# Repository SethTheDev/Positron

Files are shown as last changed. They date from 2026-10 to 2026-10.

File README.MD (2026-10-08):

# Resonance
An open-source USB-C Audio Interface powered by an STM32F411 and using a Cirrus Logic CS43198 DAC chip.
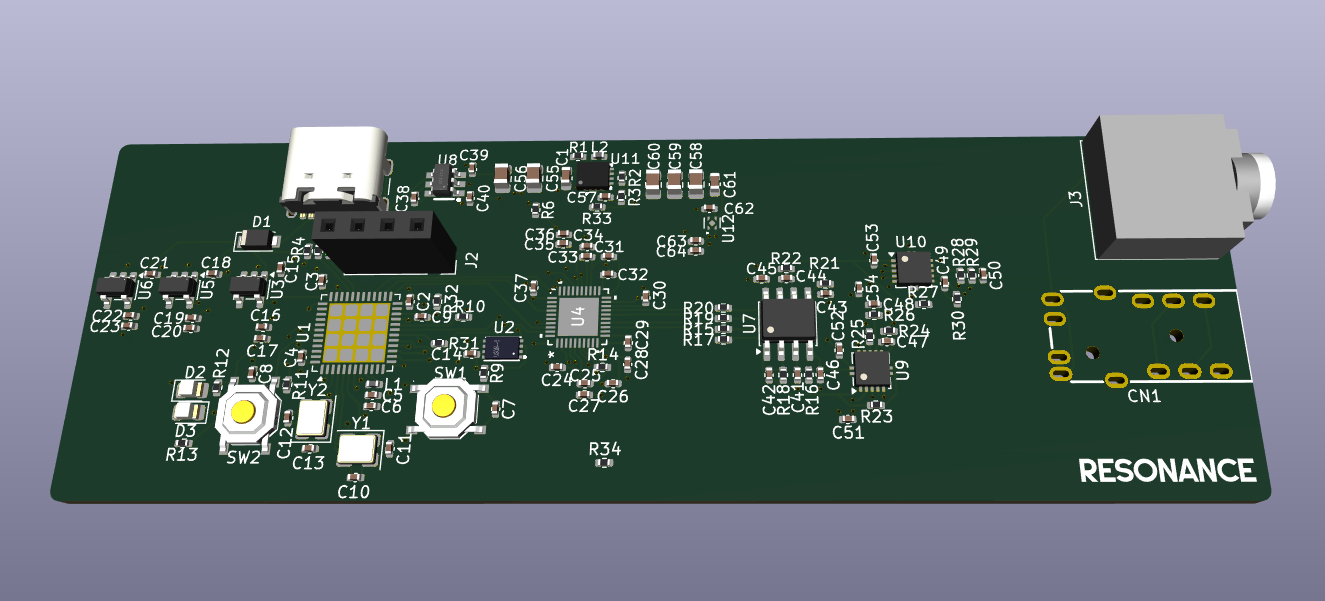
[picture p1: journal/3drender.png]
3d render


This is my magnum opus (*seriously*)

## Features
* STM32F411 microcontroller for USB audio
* Cirrus Logic CS43198 DAC with pseudo-differential output
* OPA1622 Differential Headphone Amplifier

## Rough Timeline
* (May 2026) - Raspberry Pi Pico + PCM5102
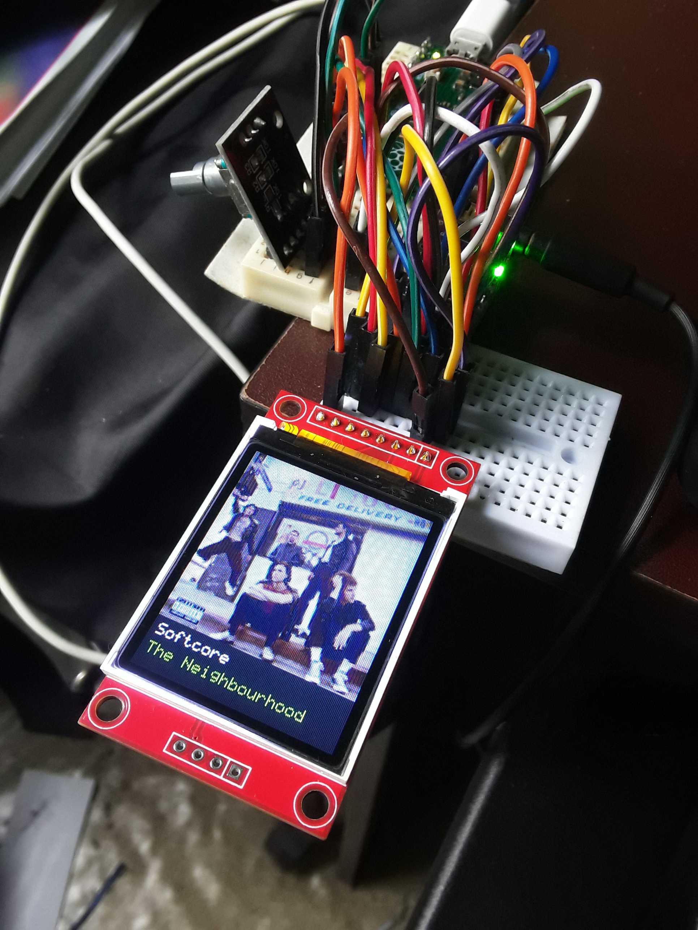
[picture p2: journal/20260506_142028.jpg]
prototype

* (August 2026) - Stuck with the Pico because of it's versatility, however I decided to use a professional Cirrus Logic CS43198 chip
* (September 2026) - Switch to an STM32H743 (way too overpowered, what was I thinking), and included a CS5361 ADC with dual-channel op-amps for two mic inputs
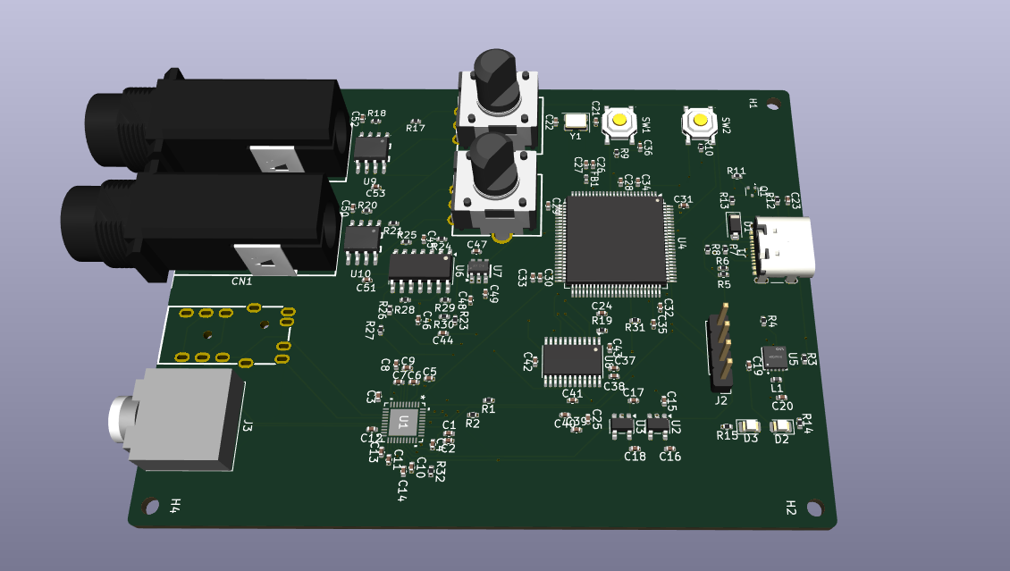
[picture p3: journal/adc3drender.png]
adc prototype

* (October 2026) - Realized I would face a lot of power-related problems so I downgraded to an STM32F411 and kept only the CS43198 DAC. Also completely revamped the schematic so it would be easy to read
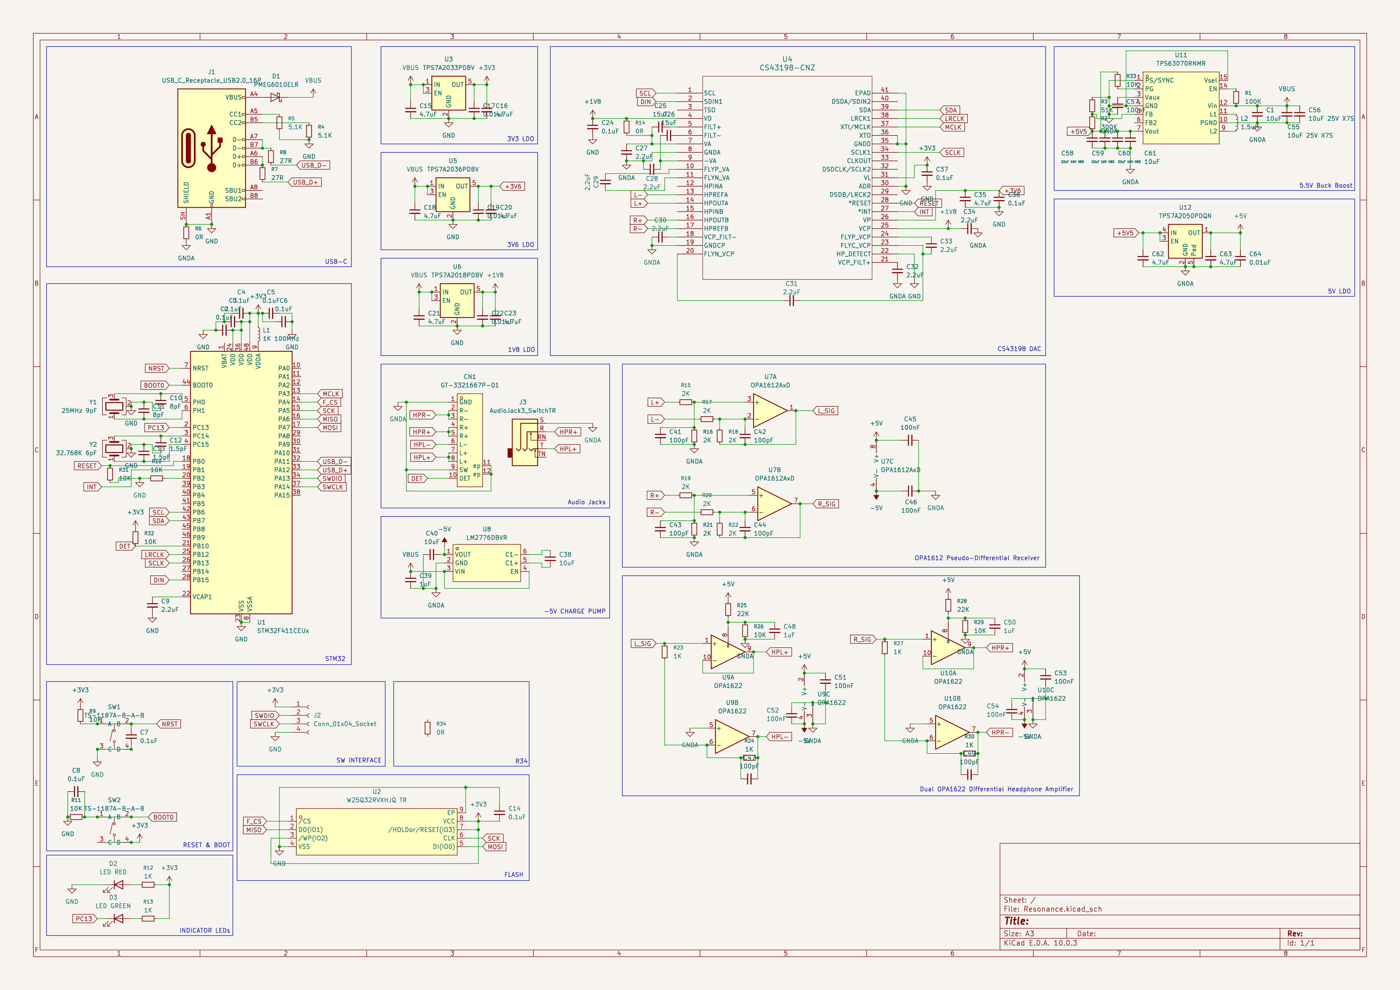
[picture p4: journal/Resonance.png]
schematic


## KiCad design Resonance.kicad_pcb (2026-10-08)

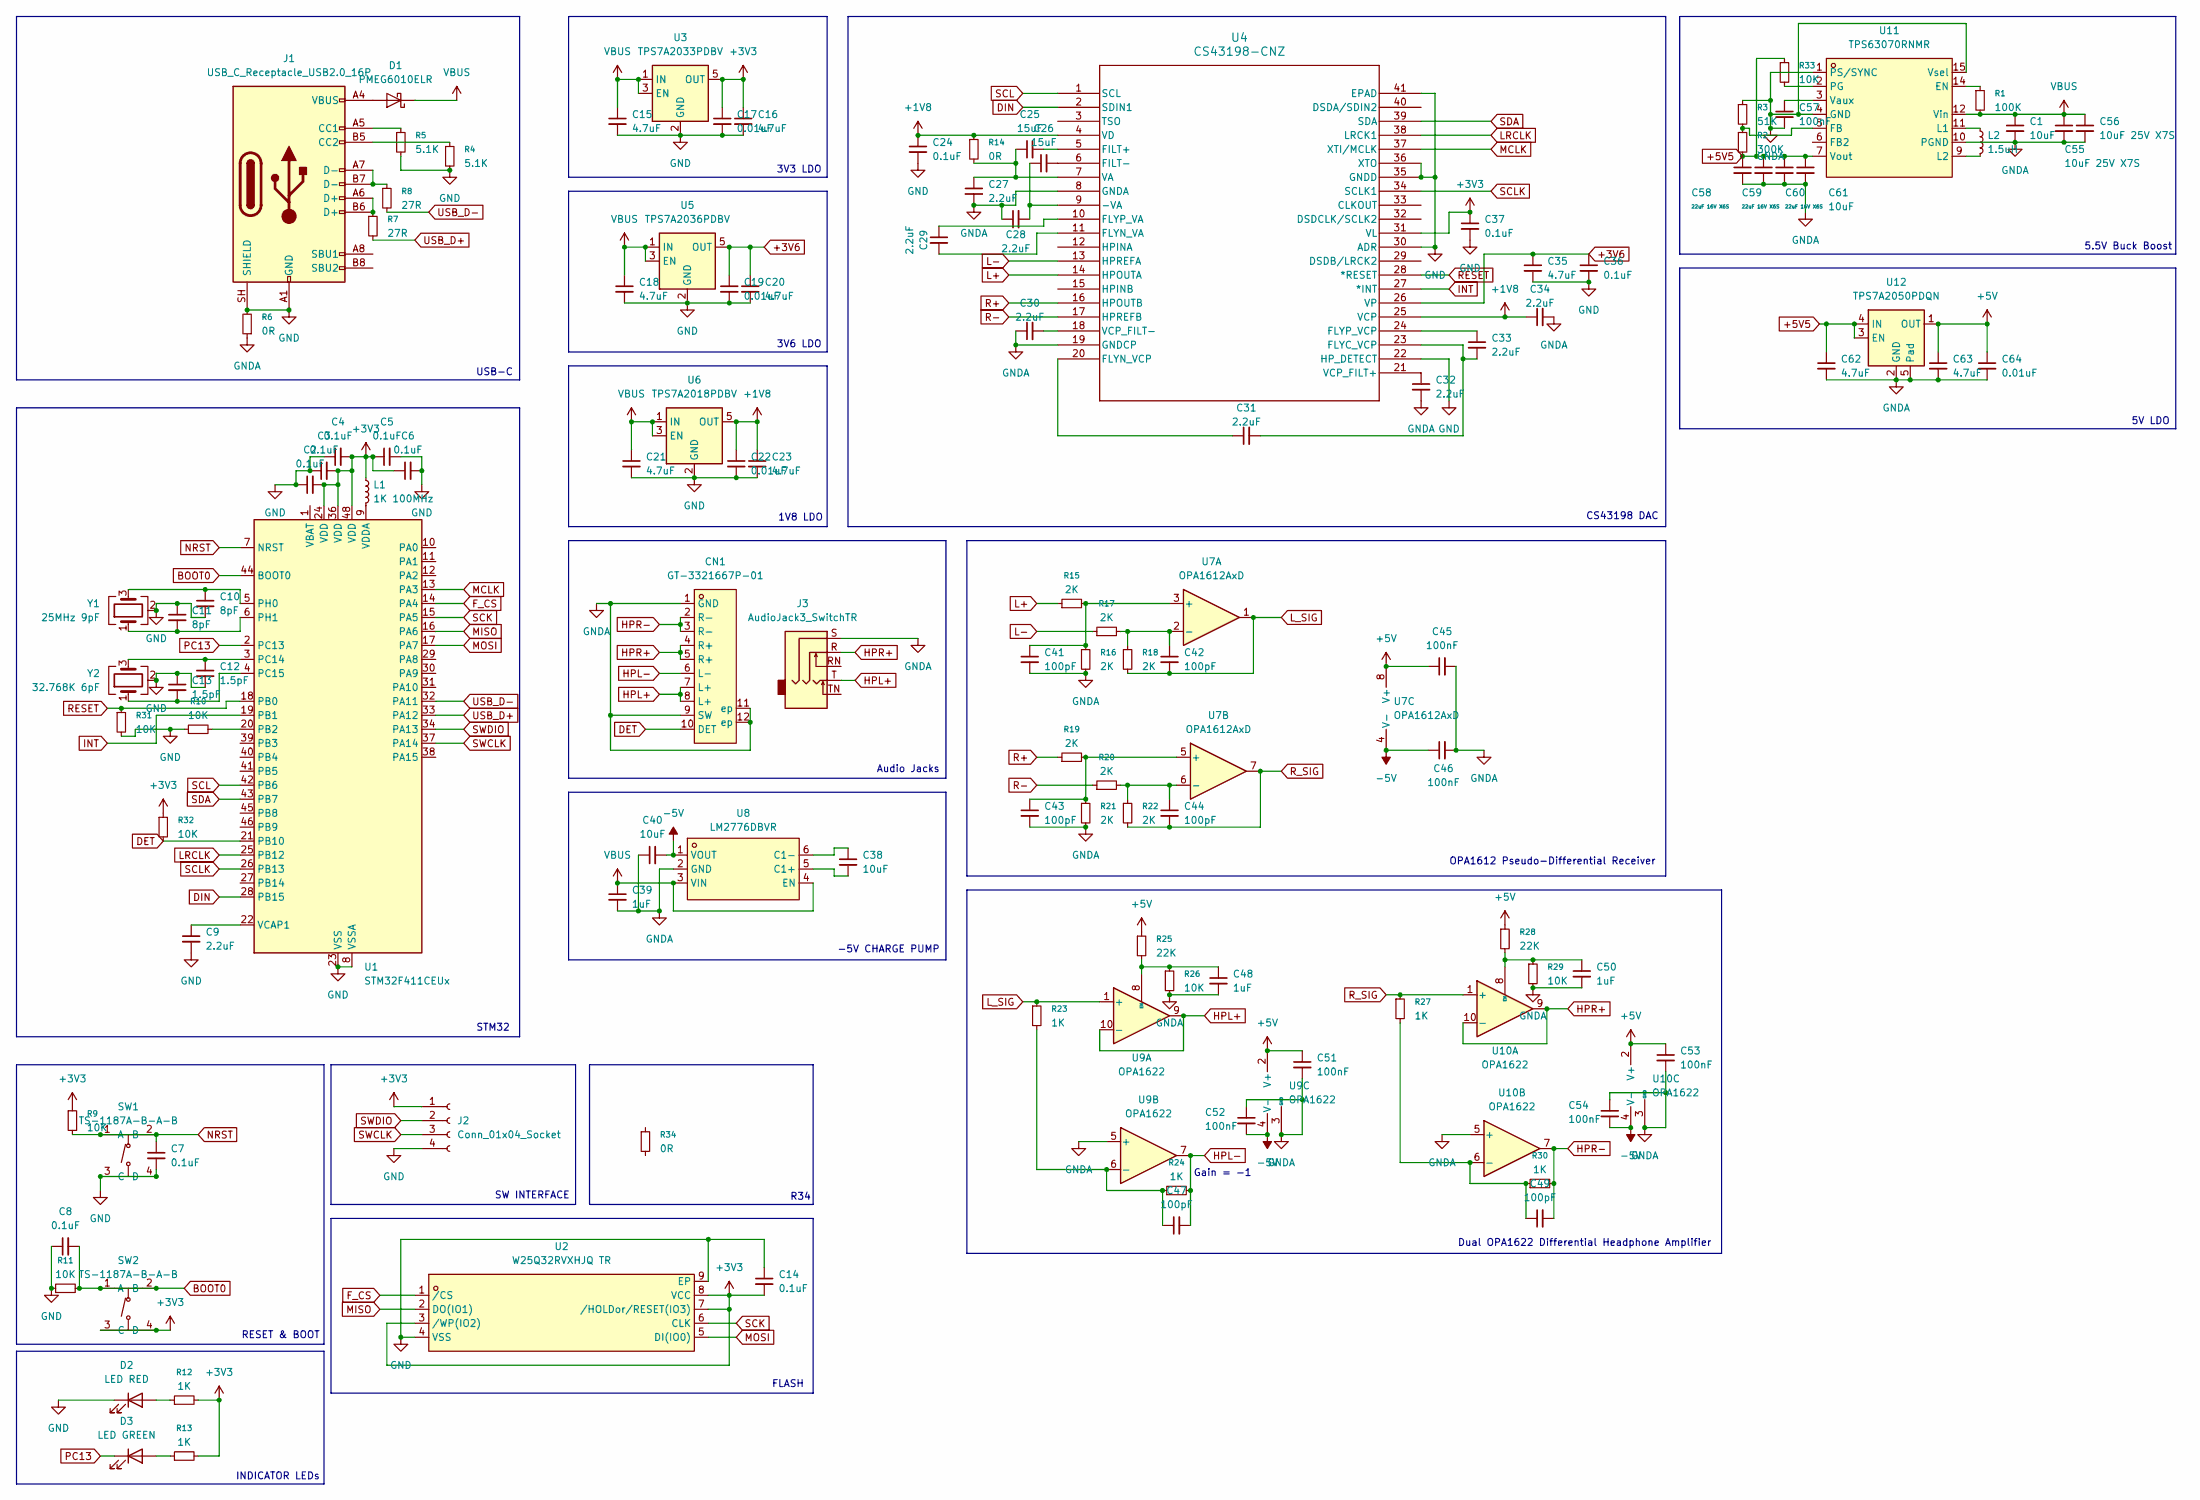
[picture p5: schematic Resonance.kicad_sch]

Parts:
C1, C61: 10uF; C_0603_1608Metric
C2, C3, C4, C5, C6, C7, C8, C14, C24, C36, C37: 0.1uF; C_0402_1005Metric
C9, C27, C28, C29, C30, C31, C32, C33, C34: 2.2uF; C_0402_1005Metric
C10, C11: 8pF; C_0402_1005Metric
C12, C13: 1.5pF; C_0402_1005Metric
C15, C16, C18, C20, C21, C23, C35, C62, C63: 4.7uF; C_0402_1005Metric
C17, C19, C22, C64: 0.01uF; C_0402_1005Metric
C25, C26: 15uF; C_0402_1005Metric
C38, C40: 10uF; C_0402_1005Metric
C39, C48, C50: 1uF; C_0402_1005Metric
C41, C42, C43, C44, C47, C49: 100pF; C_0402_1005Metric
C45, C46, C51, C52, C53, C54, C57: 100nF; C_0402_1005Metric
C55, C56: 10uF 25V X7S; C_0805_2012Metric
C58, C59, C60: 22uF 16V X6S; C_0805_2012Metric
CN1: GT-3321667P-01; AUDIO-TH_GT-3321667P-01; MPN GT-3321667P-01; LCSC Part C2762984
D1: PMEG6010ELR; Nexperia_CFP3_SOD-123W
D2: LED RED; LED_0805_2012Metric
D3: LED GREEN; LED_0805_2012Metric
J1: USB_C_Receptacle_USB2.0_16P; USB_C_Receptacle_GCT_USB4105-xx-A_16P_TopMnt_Horizontal
J2: Conn_01x04_Socket; PinSocket_1x04_P2.54mm_Vertical
J3: AudioJack3_SwitchTR; Jack_3.5mm_CUI_SJ1-3525N_Horizontal
L1: 1K 100MHz; L_0402_1005Metric
L2: 1.5uH; L_0402_1005Metric
R1: 100K; R_0402_1005Metric
R2: 300K; R_0402_1005Metric
R3: 51K; R_0402_1005Metric
R4, R5: 5.1K; R_0402_1005Metric
R6, R14, R34: 0R; R_0402_1005Metric
R7, R8: 27R; R_0402_1005Metric
R9, R10, R11, R26, R29, R31, R32, R33: 10K; R_0402_1005Metric
R12, R13, R23, R24, R27, R30: 1K; R_0402_1005Metric
R15, R16, R17, R18, R19, R20, R21, R22: 2K; R_0402_1005Metric
R25, R28: 22K; R_0402_1005Metric
SW1, SW2: TS-1187A-B-A-B; SW-SMD_4P-L5.1-W5.1-P3.70-LS6.5-TL_H1.5; MPN TS-1187A-B-A-B; LCSC Part C318884
U1: STM32F411CEUx; QFN-48-1EP_7x7mm_P0.5mm_EP5.6x5.6mm
U2: W25Q32RVXHJQ TR; USON-8_L3.0-W2.0-P0.50-BL-EP; MPN W25Q32RVXHJQ TR; LCSC Part C32246052
U3: TPS7A2033PDBV; SOT-23-5
U4: CS43198-CNZ; QFN_CS43198_CIR-M
U5: TPS7A2036PDBV; SOT-23-5
U6: TPS7A2018PDBV; SOT-23-5
U7: OPA1612AxD; SOIC-8_3.9x4.9mm_P1.27mm
U8: LM2776DBVR; SOT-23-6_L2.9-W1.6-P0.95-LS2.8-BR; MPN LM2776DBVR; LCSC Part C69527
U9, U10: OPA1622; Texas_S-PVSON-N10
U11: TPS63070RNMR; VQFN-15_L3.0-W2.5-P0.50-BL; MPN TPS63070RNMR; LCSC Part C109322
U12: TPS7A2050PDQN; Texas_X2SON-4_1x1mm_P0.65mm
Y1: 25MHz 9pF; Crystal_SMD_3225-4Pin_3.2x2.5mm
Y2: 32.768K 6pF; Crystal_SMD_3225-4Pin_3.2x2.5mm

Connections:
+1V8: C22.1, C23.1, C24.1, C34.1, R14.1, U4.4 (VD), U4.25 (VCP), U6.5 (OUT)
+3V3: C2.2, C3.2, C4.2, C5.1, C6.1, C14.2, C16.1, C17.1, C37.1, J2.1, L1.1, R9.1, R12.2, R13.2, R32.1, SW2.3 (C), SW2.4 (D), U1.24 (VDD), U1.36 (VDD), U1.48 (VDD), U2.3 (/WP(IO2)), U2.7 (/HOLDor/RESET(IO3)), U2.8 (VCC), U3.5 (OUT), U4.31 (VL)
+3V6: C19.1, C20.1, C35.1, C36.1, U4.26 (VP), U5.5 (OUT)
+5V: C45.1, C51.1, C53.1, C63.1, C64.1, R25.1, R28.1, U7.8 (V+), U9.2 (V+), U10.2 (V+), U12.1 (OUT)
+5V5: C58.1, C59.1, C60.1, C61.1, C62.1, R2.2, R33.1, U11.7 (Vout), U12.3 (EN), U12.4 (IN)
-5V: C40.2, C46.1, C52.2, C54.2, U7.4 (V-), U8.1 (VOUT), U9.4 (V-), U9.11 (V-), U10.4 (V-), U10.11 (V-)
BOOT0: C8.2, R11.2, SW2.1 (A), SW2.2 (B), U1.44 (BOOT0)
DET: CN1.10 (DET), R32.2, U1.21 (PB10)
DIN: U1.28 (PB15), U4.2 (SDIN1)
F_CS: U1.14 (PA4), U2.1 (/CS)
GND: C2.1, C3.1, C4.1, C5.2, C6.2, C7.2, C8.1, C9.2, C10.2, C11.1, C12.2, C13.1, C14.1, C15.2, C16.2, C17.2, C18.2, C19.2, C20.2, C21.2, C22.2, C23.2, C24.2, C35.2, C36.2, C37.2, D2.1 (K), J1.A1 (GND), J1.A12 (GND), J1.B1 (GND), J1.B12 (GND), J1.SH (SHIELD), J2.4, R4.2, R5.2, R6.2, R10.1, R11.1, R31.2, SW1.3 (C), SW1.4 (D), U1.8 (VSSA), U1.23 (VSS), U1.35 (VSS), U1.47 (VSS), U1.49 (VSS), U2.4 (VSS), U2.9 (EP), U3.2 (GND), U4.22 (HP_DETECT), U4.30 (ADR), U4.35 (GNDD), U4.36 (XTO), U4.41 (EPAD), U5.2 (GND), U6.2 (GND), Y1.2 (G), Y1.4 (G), Y2.2 (G), Y2.4 (G)
GNDA: C1.2, C27.2, C28.1, C30.1, C32.2, C34.2, C39.2, C40.1, C41.2, C43.2, C45.2, C46.2, C48.2, C50.2, C51.2, C52.1, C53.2, C54.1, C55.2, C56.2, C57.2, C58.2, C59.2, C60.2, C61.2, C62.2, C63.2, C64.2, CN1.1 (GND), CN1.9 (SW), CN1.11 (ep), CN1.12 (ep), J3.S, R3.1, R6.1, R16.2, R21.2, R26.2, R29.2, U4.8 (GNDA), U4.19 (GNDCP), U8.2 (GND), U9.3 (GND), U9.5 (+), U10.3 (GND), U10.5 (+), U11.1 (PS/SYNC), U11.4 (GND), U11.10 (PGND), U11.15 (Vsel), U12.2 (GND), U12.5 (Pad)
HPL+: CN1.7 (L+), CN1.8 (L+), J3.T, U9.9, U9.10 (-)
HPL-: C47.2, CN1.6 (L-), R24.2, U9.7
HPR+: CN1.4 (R+), CN1.5 (R+), J3.R, U10.9, U10.10 (-)
HPR-: C49.2, CN1.2 (R-), CN1.3 (R-), R30.2, U10.7
INT: U1.19 (PB1), U4.27 (*INT)
L+: R15.1, U4.14 (HPOUTA)
L-: R17.1, U4.13 (HPREFA)
LRCLK: U1.25 (PB12), U4.38 (LRCK1)
L_SIG: C42.2, R18.2, R23.1, U7.1, U9.1 (+)
MCLK: U1.13 (PA3), U4.37 (XTI/MCLK)
MISO: U1.16 (PA6), U2.2 (DO(IO1))
MOSI: U1.17 (PA7), U2.5 (DI(IO0))
NRST: C7.1, R9.2, SW1.1 (A), SW1.2 (B), U1.7 (NRST)
unnamed: D1.2 (A), J1.A4 (VBUS), J1.A9 (VBUS), J1.B4 (VBUS), J1.B9 (VBUS)
unnamed: D2.2 (A), R12.1
unnamed: D3.2 (A), R13.1
unnamed: J1.A5 (CC1), R5.1
unnamed: J1.B5 (CC2), R4.1
unnamed: J1.A6 (D+), J1.B6 (D+), R7.1
unnamed: J1.A7 (D-), J1.B7 (D-), R8.1
unnamed: R10.2, U1.20 (PB2)
unnamed: C12.1, U1.3 (PC14), Y2.3
unnamed: C13.2, U1.4 (PC15), Y2.1
unnamed: C10.1, U1.5 (PH0), Y1.3
unnamed: C11.2, U1.6 (PH1), Y1.1
unnamed: C9.1, U1.22 (VCAP1)
unnamed: L1.2, U1.9 (VDDA)
unnamed: C26.1, C28.2, U4.9 (-VA)
unnamed: C25.2, U4.5 (FILT+)
unnamed: C26.2, U4.6 (FILT-)
unnamed: C31.2, C33.2, U4.23 (FLYC_VCP)
unnamed: C29.2, U4.11 (FLYN_VA)
unnamed: C31.1, U4.20 (FLYN_VCP)
unnamed: C29.1, U4.10 (FLYP_VA)
unnamed: C33.1, U4.24 (FLYP_VCP)
unnamed: C25.1, C27.1, R14.2, U4.7 (VA)
unnamed: C32.1, U4.21 (VCP_FILT+)
unnamed: C30.2, U4.18 (VCP_FILT-)
unnamed: C41.1, R15.2, R16.1, U7.3 (+)
unnamed: C42.1, R17.2, R18.1, U7.2 (-)
unnamed: C43.1, R19.2, R21.1, U7.5 (+)
unnamed: C44.1, R20.2, R22.1, U7.6 (-)
unnamed: C38.2, U8.5 (C1+)
unnamed: C38.1, U8.6 (C1-)
unnamed: C48.1, R25.2, R26.1, U9.8 (EN)
unnamed: C47.1, R23.2, R24.1, U9.6 (-)
unnamed: C50.1, R28.2, R29.1, U10.8 (EN)
unnamed: C49.1, R27.2, R30.1, U10.6 (-)
unnamed: R1.1, U11.14 (EN)
unnamed: R2.1, R3.2, U11.5 (FB)
unnamed: L2.1, U11.11 (L1)
unnamed: L2.2, U11.9 (L2)
unnamed: R33.2, U11.2 (PG)
unnamed: C57.1, U11.3 (Vaux)
PC13: D3.1 (K), U1.2 (PC13)
R+: R19.1, U4.16 (HPOUTB)
R-: R20.1, U4.17 (HPREFB)
RESET: R31.1, U1.18 (PB0), U4.28 (*RESET)
R_SIG: C44.2, R22.2, R27.1, U7.7, U10.1 (+)
SCK: U1.15 (PA5), U2.6 (CLK)
SCL: U1.42 (PB6), U4.1 (SCL)
SCLK: U1.26 (PB13), U4.34 (SCLK1)
SDA: U1.43 (PB7), U4.39 (SDA)
SWCLK: J2.3, U1.37 (PA14)
SWDIO: J2.2, U1.34 (PA13)
USB_D+: R7.2, U1.33 (PA12)
USB_D-: R8.2, U1.32 (PA11)
VBUS: C1.1, C15.1, C18.1, C21.1, C39.1, C55.1, C56.1, D1.1 (K), R1.2, U3.1 (IN), U3.3 (EN), U5.1 (IN), U5.3 (EN), U6.1 (IN), U6.3 (EN), U8.3 (VIN), U8.4 (EN), U11.12 (Vin)

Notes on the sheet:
RESET & BOOT
STM32
FLASH
USB-C
Dual OPA1622 Differential Headphone Amplifier
INDICATOR LEDs
R34
CS43198 DAC
-5V CHARGE PUMP
5V LDO
SW INTERFACE
OPA1612 Pseudo-Differential Receiver
1V8 LDO
5.5V Buck Boost
Audio Jacks
Gain = -1
3V3 LDO
3V6 LDO

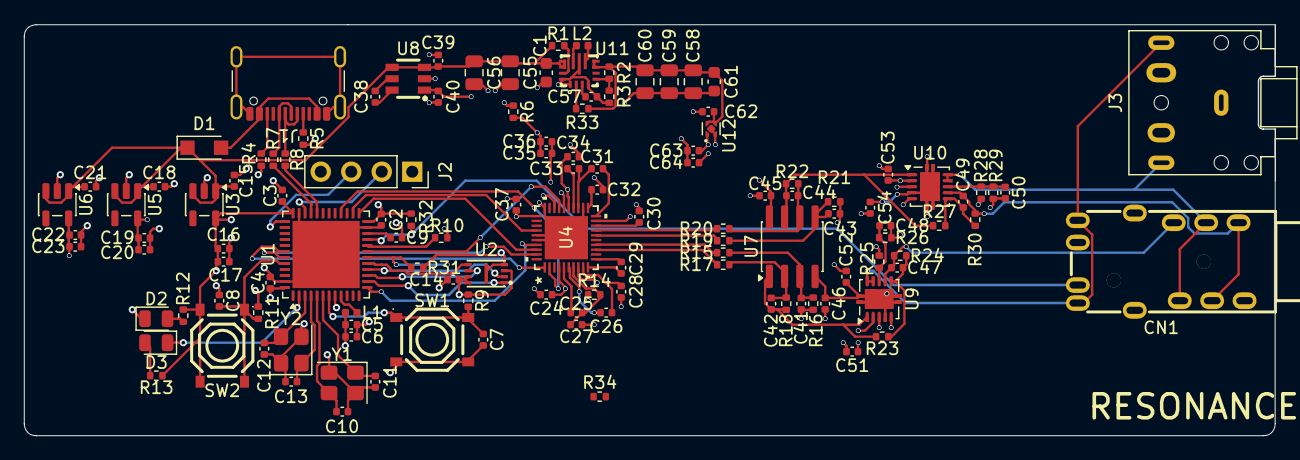
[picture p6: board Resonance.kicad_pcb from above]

Board: 4 copper layers, 104.3 x 34.2 mm, 123 parts (0 on the bottom side), 80 nets.

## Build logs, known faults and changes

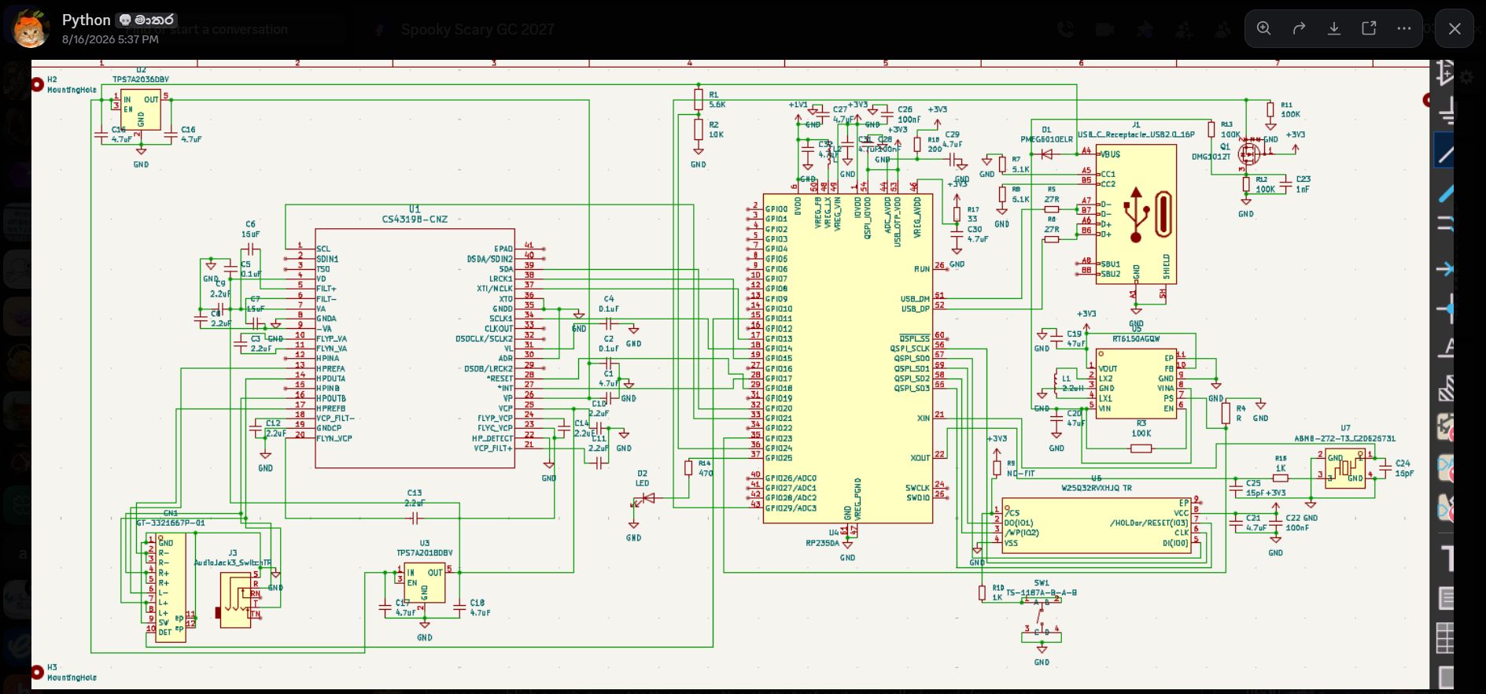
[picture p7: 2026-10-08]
journal/Screenshot 2026-10-07 125742.png

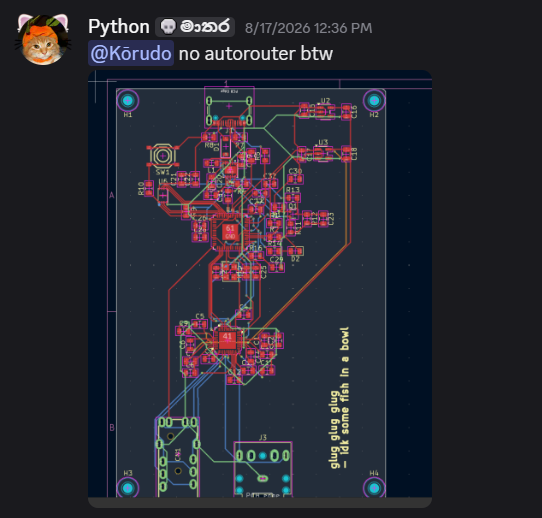
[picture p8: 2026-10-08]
journal/Screenshot 2026-10-07 125803.png

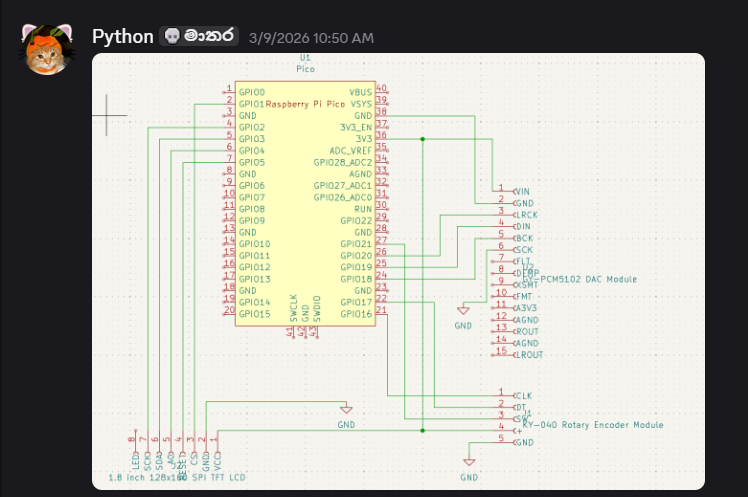
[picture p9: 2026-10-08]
journal/Screenshot 2026-10-07 124845.png

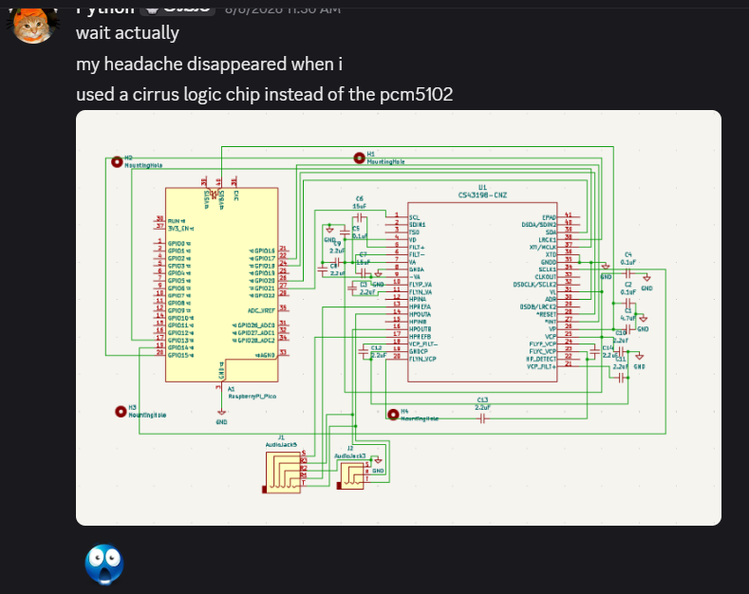
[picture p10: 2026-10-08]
journal/Screenshot 2026-10-07 125621.png

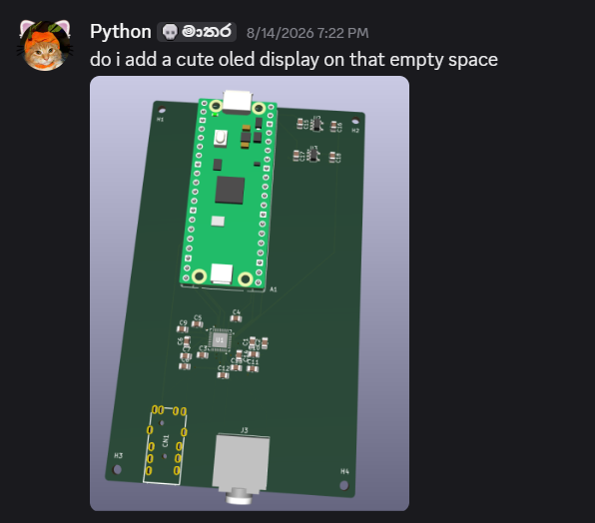
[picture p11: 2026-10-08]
journal/Screenshot 2026-10-07 125707.png

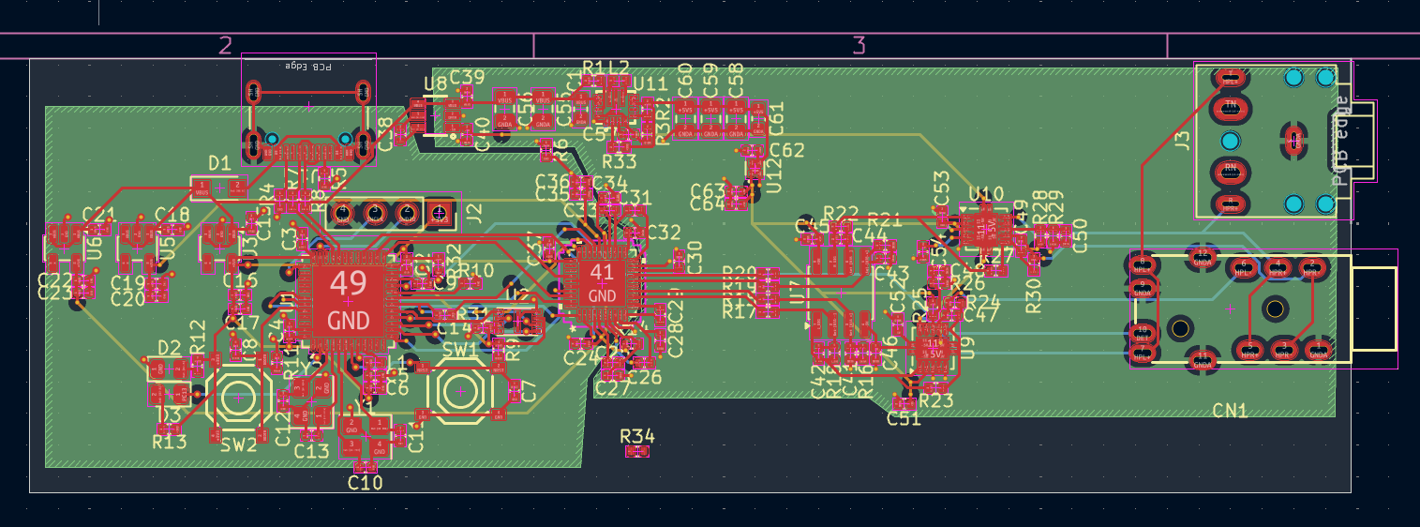
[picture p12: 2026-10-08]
journal/Screenshot 2026-10-07 130129.png

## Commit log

2026-08-29 fix balanced mic input
    [Positron.kicad_pcb, Positron.kicad_sch]
2026-09-15 separate GND planes and fill copper zone
    [Positron.kicad_pcb, Positron.kicad_sch]
2026-10-07 completely revamp schematic, switch to STM32F411, remove ADC/mic preamps, add clean +5V rail, add headphone amp stage
    [Positron-B_Cu.gbr, Positron-B_Mask.gbr, Positron-B_Paste.gbr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]
2026-10-08 add readme
    [Resonance.kicad_pcb, Resonance.kicad_sch]
